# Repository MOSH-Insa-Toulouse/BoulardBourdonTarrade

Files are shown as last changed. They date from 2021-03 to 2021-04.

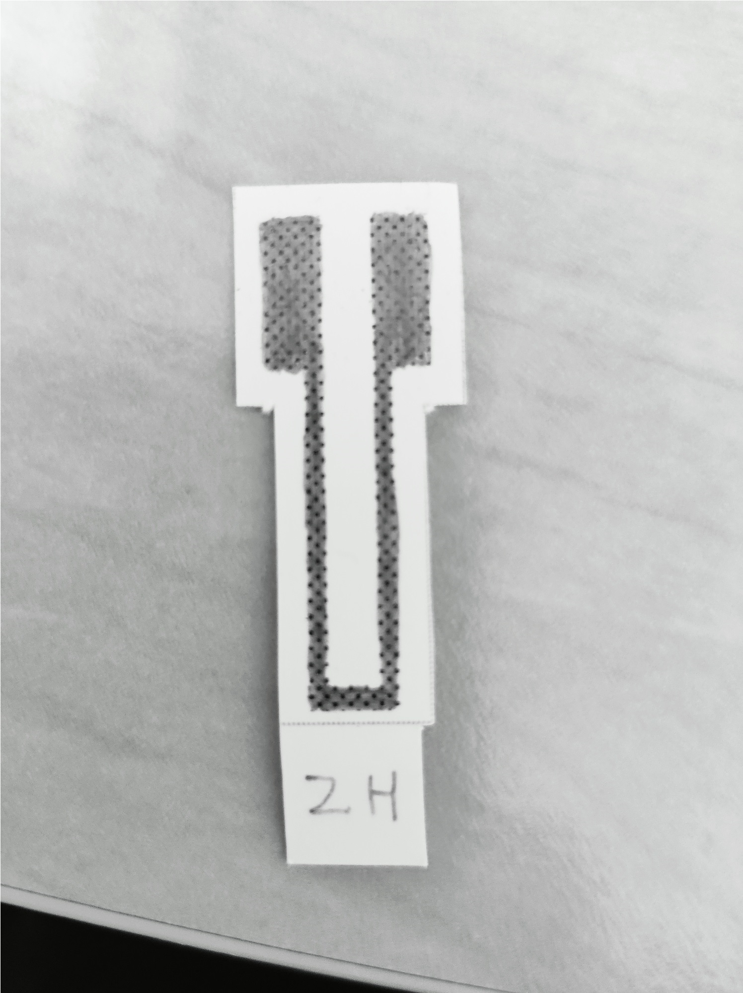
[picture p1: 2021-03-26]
Images/IMG_20210308_161819.jpg

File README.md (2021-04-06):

# Projet Capteur  

This project is a Master's degree project at INSA - Toulouse.

  - [Installation](#installation)
  - [Usage](#usage)
  - [Arduino Code](#arduino-code)
  - [Shield](#shield)
  - [APK](#apk)
  - [Datasheet](#datasheet)
  - [Credits](#credits)
  - [Roadmap](#roadmap)

## Installation

  * Use the Gerber folder to create the Arduino Shield.  
  * Once created, use the datasheet schematics to solder all the components onto the shield.  
  * When the shield is completed, plug it onto an Arduino Uno.  
  * Transfer the program, found in Project in the master level, into the Arduino.
  * You are then good to go! You can now start measuring different electrical resistances with your sensor. 
  * In addition to displaying the datas onto the OLED screen, you can also choose to display them on the Serial Plotter of the Arduino, or you can download our mobile    phone app (see section APK). 

## Usage

The Arduino Uno is able to measure the tension and the resistance of your sensor as is. 

However, if you want to measure the deflection of the sensor, you will need to use the 2 points calibration menu, named "Etalon 2 points". 
First, simply straighten the sensor and press the rotary encoder once. This will calibrate the resistance at the sensor's rest position (R0). 
Afterwards, rotate the same encoder to a chosen angle of deflection, before applying said angle onto the sensor. Once applied, press the encoder once. Repeat this step and press the encoder again to finalise the calibration. 

After completing the calibration, all calibration values (R0, slope and offset) can be found in the menu entitled "Menu Calibration".

## Arduino Code

The full Arduino code is available in the GitHub "Projet" folder, it is entirely commented and can be modified at will.

## Shield

All the details related to the shield are available in the "Shield Uno" and the "Gerber" folders, which can be modified at will by using the electronic design automation software called KiCad.

## APK

The mobile application, defined by its extension .apk, was created using the tools on MIT's AppInventor website. If necessary, the application can be modified using this same tool. However, to do so, you will need the .aia file used to create the application. Both the .apk and .aia files can be found in the Master level of the GitHub.

## Datasheet

All the details concerning the sensor is available in our datasheet, which is composed of a primary pdf file and a complementary Excel sheet (.xlsx).

## Created by

BOULARD Tanguy  
BOURDON Léo  
TARRADE Manon  

## Roadmap

  - [x] Build the shield
  - [x] Program a first version of the Arduino Code
  - [x] Create the mobile application which displays and saves the datas measured by the sensor
  - [x] Create the datasheet of the sensor
  - [x] Add a 2 points calibration menu in the Arduino Code
  - [ ] Add a Test Bench menu on the Arduino
  - [ ] Make the sensor more reliable

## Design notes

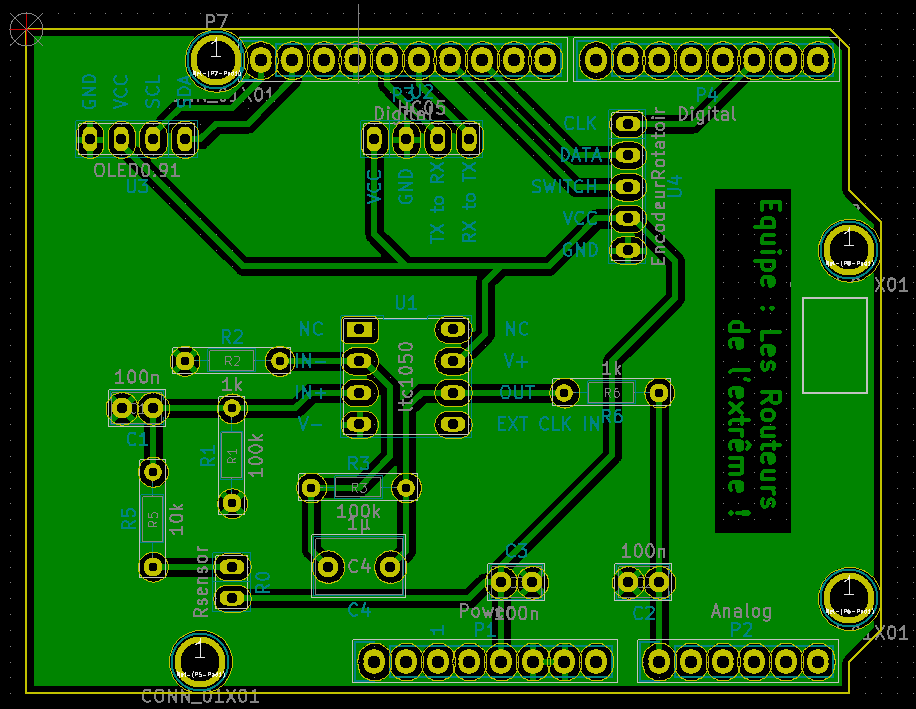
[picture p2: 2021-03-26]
Images/PCB.png

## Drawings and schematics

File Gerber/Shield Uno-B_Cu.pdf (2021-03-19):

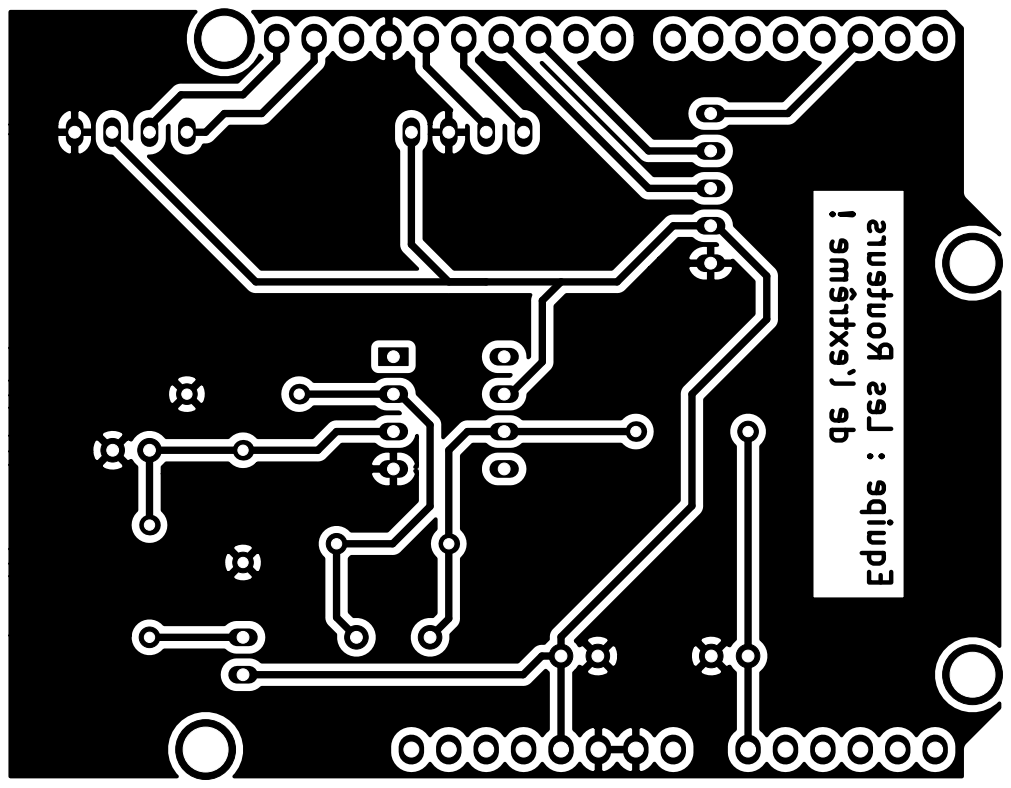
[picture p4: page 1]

INSA - Toulouse Bourdon - Boulard - Tarrade Opérateurs CAO: Les Routeurs de l'extrême Equipe : Les Routeurs de l'extrême !

File: Shield Uno.kicad_pcb Sheet:
Id: 1/1 Title: PCB Shield Uno Projet

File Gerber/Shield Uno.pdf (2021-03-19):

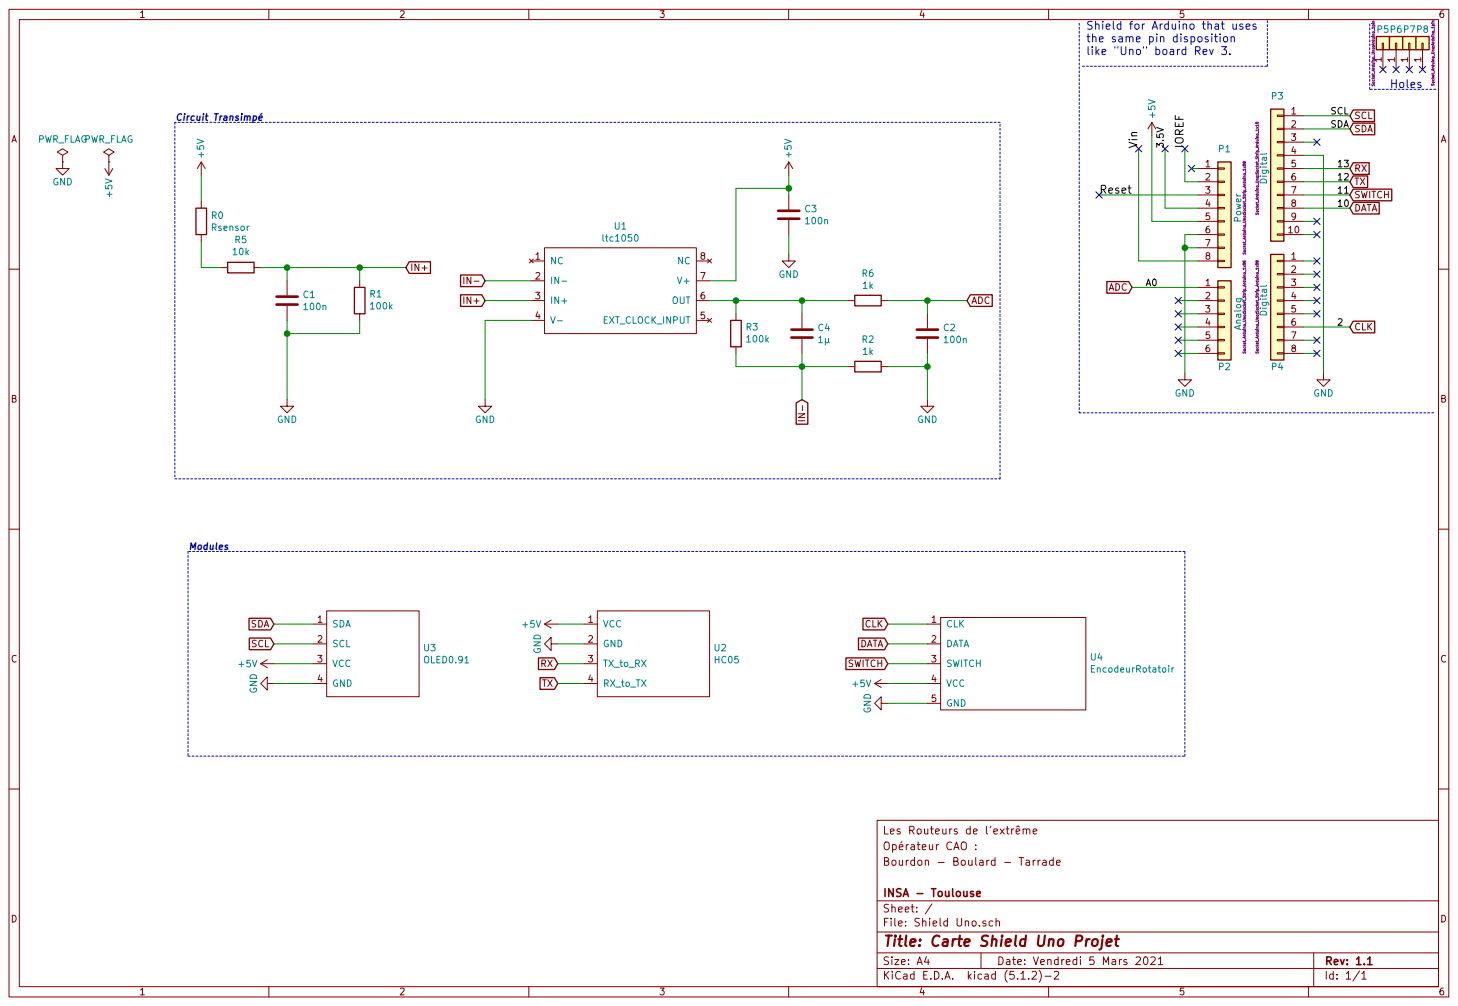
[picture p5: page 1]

Holes Shield for Arduino that uses
the same pin disposition

INSA - Toulouse Bourdon - Boulard - Tarrade Opérateur CAO : Les Routeurs de l'extrême

Id: 1/1 Title: Carte Shield Uno Projet File: Shield Uno.sch Sheet: /

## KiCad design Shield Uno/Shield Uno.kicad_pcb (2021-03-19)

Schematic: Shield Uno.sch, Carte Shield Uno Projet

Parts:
C1, C2, C3: 100n; C_Rect_L4.0mm_W2.5mm_P2.50mm
C4: 1µ; C_Rect_L7.0mm_W4.5mm_P5.00mm
P1: Power; Socket_Strip_Arduino_1x08
P2: Analog; Socket_Strip_Arduino_1x06
P3: Digital; Socket_Strip_Arduino_1x10
P4: Digital; Socket_Strip_Arduino_1x08
P5, P6, P7, P8: CONN_01X01; Arduino_1pin
R0: Rsensor
R1, R3: 100k; R_Axial_DIN0204_L3.6mm_D1.6mm_P7.62mm_Horizontal
R2, R6: 1k; R_Axial_DIN0204_L3.6mm_D1.6mm_P7.62mm_Horizontal
R5: 10k; R_Axial_DIN0204_L3.6mm_D1.6mm_P7.62mm_Horizontal
U1: ltc1050
U2: HC05
U3: OLED0.91; OLED
U4: EncodeurRotatoir; RotoEncodeur

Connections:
+5V: C3.1, P1.5, R0.1, U1.7, U2.1 (VCC), U3.3, U4.4 (VCC)
/3.5V: P1.4
/IOREF: P1.2
/Reset: P1.3
/Vin: P1.8
ADC: C2.1, P2.1, R6.1
CLK: P4.6, U4.1 (CLK)
DATA: P3.8, U4.2 (DATA)
GND: C1.2, C2.2, C3.2, P1.6, P1.7, P3.4, R1.1, R2.1, U1.4, U2.2 (GND), U3.4, U4.5 (GND)
IN+: C1.1, R1.2, R5.2, U1.3
IN-: C4.2, R2.2, R3.1, U1.2
unnamed: C4.1, R3.2, R6.2, U1.6
unnamed: R0.2, R5.1
RX: P3.5, U2.3 (TX_to_RX)
SCL: P3.1, U3.2
SDA: P3.2, U3.1
SWITCH: P3.7, U4.3 (SWITCH)
TX: P3.6, U2.4 (RX_to_TX)

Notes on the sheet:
Holes
Shield for Arduino that uses the same pin disposition like "Uno" board Rev 3.
Modules
Circuit Transimpé

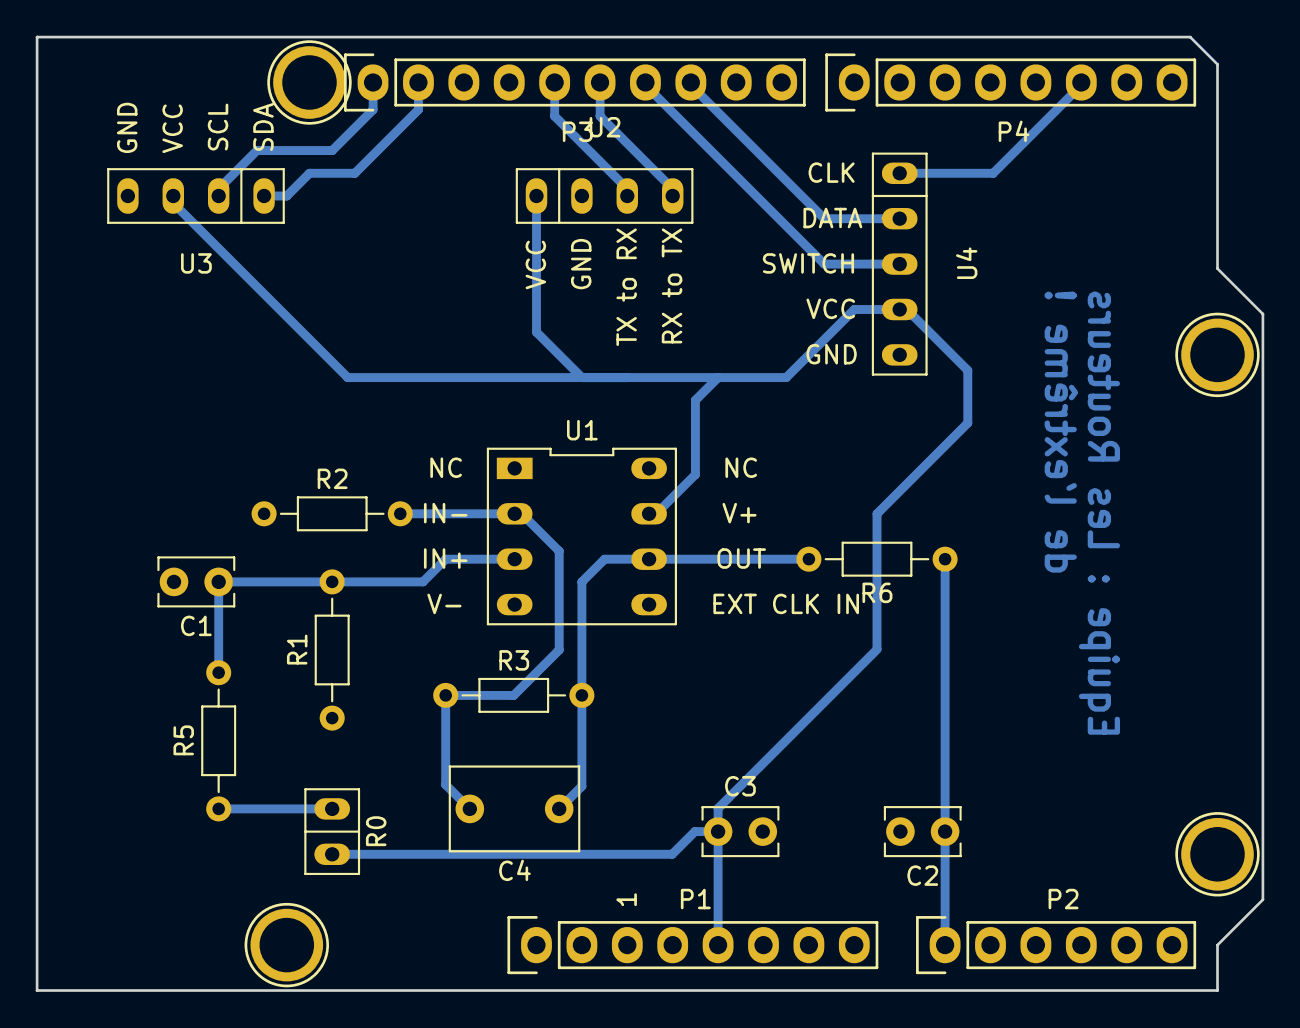
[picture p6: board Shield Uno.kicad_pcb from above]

Board: 2 copper layers, 68.6 x 53.3 mm, 22 parts (0 on the bottom side), 14 nets.

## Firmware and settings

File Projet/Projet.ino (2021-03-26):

//=============================Bluetooth Module=====================
#include <SoftwareSerial.h>

#define rxPin 13
#define txPin 12
#define baudrate 9600
SoftwareSerial mySerial(rxPin,txPin);

//=============================Roto Encoder=========================
#define encoderPinA  2  //The clock signal of the Roto Encoder must be on the pin 2 since we want to use an attachInterrupt on it 
#define encoderPinB  10  //DT signal of the Roto Encoder
#define Switch 11 //SW signal of the Roto Encoder

int aState; //State of the pin A of the Roto Encoder
int aLastState;  //Last state of the pin A of the Roto Encoder
int btnState = HIGH; //State of the button 
int btnLastState = HIGH; //Last state of the button

//=============================OLED Screen==========================
#include <SPI.h>
#include <Wire.h>
#include <Adafruit_GFX.h>
#include <Adafruit_SSD1306.h>
#define SCREEN_WIDTH 128 //OLED display width, in pixels
#define SCREEN_HEIGHT 32 //OLED display height, in pixels

#define OLED_RESET -1 //Reset pin shared with the arduino reset button
#define SCREEN_ADDRESS 0x3C //Adress of the OLED Screen
Adafruit_SSD1306 display(SCREEN_WIDTH, SCREEN_HEIGHT, &Wire, OLED_RESET);

//=============================Measure==============================
#define pinAnalog A0 //Pin used to measure the Sensor

//Var used to measure
float mesure = 0.0; //Deflection
float valeur = 0.0; //Tension (0 = 0V; 1024 = 5V)
float resistance = 0.0; //Resistance of the Sensor
float moyenne[10]; //Last ten values of the tension
float moy = 0.0; //Mean value of the tension
float R0 = 0.0; //Resistance at rest of the Sensor

//we suppose that deflection = Slope * DeltaR + Offset
float sensi = 8.55; //Slope of the Sensor 
float offset = -25.1; //Offset of the Sensor

//Var used for the two points calibration
int etalonnage2Points = 0; 
float courbure = 0.0;
float mesurePoint1 = 0.0;
float mesurePoint2 = 0.0;
float courburePoint1 = 0.0;
float courburePoint2 = 0.0;

//=============================Timer================================
int rotoT0 = millis();
int rotoTimer = millis();

int T0 = millis();
int Timer = millis();

//=============================Menu=================================
int mode = 1; //Var that tells in which menu you are
int selection = 1; //Var used to select which menu you want to go to

//=============================Setup================================
/*Function used at the start of the Arduino*/
void setup(){
  //Initialization of the Bluetooth module
  pinMode(rxPin, INPUT);
  pinMode(txPin, OUTPUT);
  mySerial.begin(baudrate);
  
  //Initialization of the Roto Encoder
  pinMode(encoderPinA, INPUT);
  digitalWrite(encoderPinA, HIGH);
  pinMode(encoderPinB, INPUT);
  digitalWrite(encoderPinB, HIGH);
  attachInterrupt(digitalPinToInterrupt(2), doEncoder, RISING);
  aLastState = digitalRead(encoderPinA);

  pinMode(Switch, INPUT_PULLUP);

  //Initialization of the OLED Screen
  display.begin(SSD1306_SWITCHCAPVCC, SCREEN_ADDRESS);
  display.display();
  delay(2000);
  
  for(int i = 0; i < 60; i++){
    Introduction(i);
  }
  delay(2000);
  
  Serial.begin(baudrate);

  //We measure the resistance at rest of the Sensor
  valeur = (float)(analogRead(pinAnalog) * (float)(5.0/1024.0));
  R0 = (float)((1.0+100000.0/1000.0)*100000.0*(5.0/valeur)-100000.0-10000.0)/1000000.0 ;
}

//=============================Main Loop============================
/*Function used every X ms*/
void loop() {
  //Updating timers
  rotoTimer = millis();

  //We measure the tension on the pin A0
  valeur = (float)(analogRead(pinAnalog) * (float)(5.0/1024.0));

  //We store the value in a table which contains the last ten values of the tension
  for(int j = 0; j < 9;  j++){
    moyenne[j] = moyenne[j+1];
  }
  
  //We calculate the average value of this table
  moyenne[9] = valeur;
  moy = 0.0;
  for(int j = 0; j < 10;  j++){
    moy += moyenne[j];
  }
  moy = (float)moy/10.0;

  //We calculate the value of the resistance
  if(moy != 0){
    resistance = (float)((1.0+100000.0/1000.0)*100000.0*(5.0/moy)-100000.0-10000.0)/1000000.0 ;
  }else{
    resistance = -1;
  }
  mesure = (float)(resistance * sensi) + offset;

  //We send the value to the computer
  if(Serial.available()){Serial.println(resistance);}

  int i = 0;
  char textBluetooth[32] = {0};
  /*Communication from the bluetooth module to the arduino*/
  while (mySerial.available()){ //While the com is open
    i = 0;
    do{ //We read what the bluetooth module send to the arduino
      textBluetooth[i++] = mySerial.read();
      delay(3);
    }while(mySerial.available());
    //if the message read is "mesure" it means the phone is waiting for the resistance's value
    String test = (String)textBluetooth;
    test.trim();
    Serial.println(test);
    if(test == "mesure"){
      //We send the resistance's value to the bluetooth module
      mySerial.print(resistance);
    }
    if(test == "R0"){
      //We send the R0's value to the bluetooth module
      mySerial.print(R0);
    }
  }

  //We uptdate the button state
  btnLastState = btnState;
  btnState = digitalRead(Switch);

  /*Switch that draws on the screen the right menu*/
  display.clearDisplay();
  display.drawRect(1, 1, 126,31, WHITE);
  switch (mode){
    case 1:
      //Measurement menu
      MenuMesure();
      if(btnState == LOW and btnLastState != LOW){mode = 5;}
      break;
    case 2:
      //Calibration menu
      MenuEtalonnage();
      if(btnState == LOW and btnLastState != LOW){mode = 5;}
      break;
    case 3:
      //2 points calibration menu
      MenuEtalonnage2Points();
      if(btnState == LOW and btnLastState != LOW){
        etalonnage2Points += 1;
        if(etalonnage2Points == 3){
          mode = 5;
          etalonnage2Points = 0;
          //Once the calibration is done we calculate the slope and the offset
          sensi = ((mesurePoint2 - mesurePoint1)/(courburePoint2 - courburePoint1));
          offset = (mesurePoint1 - (sensi * courburePoint1));
          selection = 1;
        }
      }
      break;
    case 5:
      //Menu in which you can choose which menu to go to 
      MenuChoix();
      if(btnState == LOW and btnLastState != LOW){mode = selection; etalonnage2Points = 0; courbure = 0;}
      break;
    default:
      MenuMesure();
      if(btnState == LOW and btnLastState != LOW){mode = 5;}
      break;
  }
}


//=============================Roto Encoder=========================
/*Function that detects when the Roto Encoder spins*/
void doEncoder() {
  if(rotoTimer - rotoT0 > 50 ){
    if (digitalRead(encoderPinB) != digitalRead(encoderPinA) and digitalRead(encoderPinB) != digitalRead(encoderPinA)){
      selection ++;
      switch (mode){
        case 3:
          courbure+=0.25;
          break;
        default:
          break;
        }
    }else{
      selection --;
      switch (mode){
        case 3:
          courbure-=0.25;
          break;
        default:
          break;
      }
    }

    if(selection > 3){selection = 1;}
    if(selection < 1){selection = 3;}
    rotoT0 = millis();
  }
}

//=============================OLED Text Drawing====================
/*Function that draws text on the OLED Screen*/
void Affichage(String text, int x, int y, int taille, boolean actualiser){
  display.setTextSize(taille);
  display.setTextColor(WHITE);
  display.setCursor(x,y);
  display.println(text);
  if(actualiser){
    display.display();
  }
}

//=============================Measurement Menu=====================
/*Function that draws the measurement menu every 300 ms*/
void MenuMesure(){
  if(Timer - T0 > 300){
    Affichage("Tension :", 4, 3, 1, false);
    String text = String(valeur * 1000.0);
    String text1 = String(resistance);
    if(resistance == -1){text1 = "inf";}    
    String text2 = String(mesure);
    Affichage(text, 60, 3, 1, false);
    Affichage("mV", 100, 3, 1, false);
    Affichage("Res:", 4, 11, 1, false);
    Affichage(text1, 40, 11, 1, false);
    Affichage("MOhm", 100, 11, 1, false);
    Affichage(text2, 60, 21,1,false);
    Affichage("Courbure:", 4, 21, 1, false);
    Affichage("mm", 100, 21, 1, true);
    T0 = millis();
  }
  Timer = millis();
}

//=============================Main Menu============================
/*Function that draws the main menu*/
void MenuChoix(){
  Affichage("Menu Mesure", 4, 3, 1, false);
  Affichage("Menu Calibration", 4, 11, 1, false);
  Affichage("Etalon 2 Points", 4, 21, 1, false);
  switch (selection){
    case 1:
      Affichage("<", 110, 3, 1, true);
      break;
    case 2:
      Affichage("<", 110, 11, 1, true);
      break;
    case 3:
      Affichage("<", 110, 21, 1, true);
      break;
    default:
      Affichage("<", 110, 3, 1, true);
      break;
  }
}

//=============================Calibration Menu=====================
/*Function that draws the calibration menu*/
void MenuEtalonnage(){
  String text1 = String(sensi);
  String text2 = String(offset);
  Affichage("Sensi:", 4, 3, 1, false);
  Affichage(text1, 72, 3, 1, false);
  Affichage("Offset:", 4, 11, 1, false);
  Affichage(text2, 72, 11, 1, false);
  String R0string = String(R0);
  Affichage("R0:", 4, 21, 1, false);
  Affichage(R0string, 72, 21, 1, false);
  Affichage("MOhm", 100, 21, 1, true);
}

//=============================2 Points Calibration Menu============
/*Function that draws the 2 points calibration menu*/
void MenuEtalonnage2Points(){
  String text = String(valeur * 1000.0);
  if(etalonnage2Points == 0){
    R0 = resistance;
    String R0string = String(R0);
    Affichage("R0:", 4, 3, 1, false);
    Affichage(R0string, 72, 3, 1, false);
    Affichage("MOhm", 100, 3, 1, false);
    Affichage("Appuyez", 4, 11, 1, false);
    Affichage("Mesure:", 4, 21, 1, false);
    Affichage(text, 72, 21, 1, false);
    Affichage("mV", 110, 21, 1, true);
  }else{
    String text1 = String(courbure);
    Affichage("Courbure :", 4, 3, 1, false);
    Affichage(text1, 72, 3, 1, false);
    Affichage("Appuyez", 4, 11, 1, false);
    Affichage("Mesure:", 4, 21, 1, false);
    Affichage(text, 72, 21, 1, false);
    Affichage("mV", 110, 21, 1, true);  
  }
  if(etalonnage2Points == 1){
    mesurePoint1 = resistance;
    courburePoint1 = courbure;
  }
  if(etalonnage2Points == 2){
    mesurePoint2 = resistance;
    courburePoint2 = courbure;
  }
}

//=============================Introduction=========================
/*Function that display our team's name*/
void Introduction(int i){
  display.clearDisplay();
  Affichage("  LES ROUTEURS DE", i-64, 7, 1, false);
  Affichage("     L'EXTREME", i-64, 15, 1, false);
  display.fillRect(i-64, 23, display.width()-8, 8, SSD1306_INVERSE);
  display.setTextColor(BLACK);
  display.setCursor(i-64,23);
  display.setTextSize(0.5);
  display.println("            Bouf INC");
  display.display();
}

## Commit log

2021-03-19 version initiale du projet
    [Shield Uno.kicad_pcb, Shield Uno.sch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]
2021-03-19 Version 1.5
    [Data sheet.xlsx]
